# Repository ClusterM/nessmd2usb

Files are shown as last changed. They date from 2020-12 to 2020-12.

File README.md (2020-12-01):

# nessmd2usb
This adapter allows to connect Sega Mega Drive (Sega Genesis) and Famiclone (9-pin and 15-pin) controllers to PC via USB. Also it allows to connect 15-pin Famicom Light Gun (or clones) and use it with [fceux](https://github.com/taSVideos/fceux/) emulator.

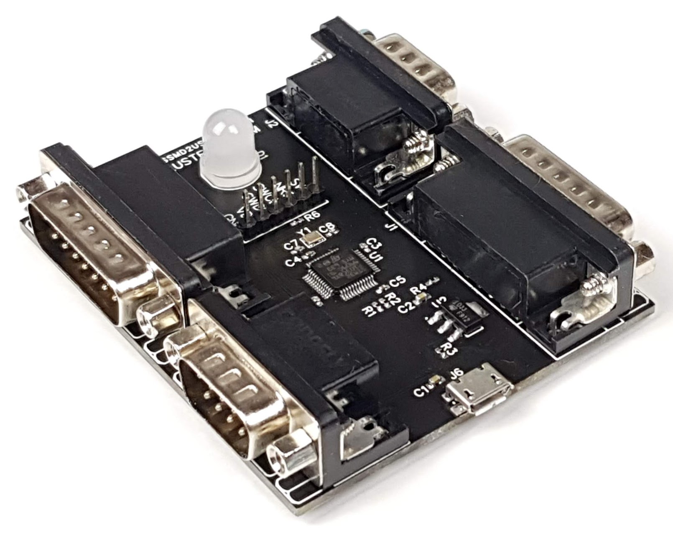
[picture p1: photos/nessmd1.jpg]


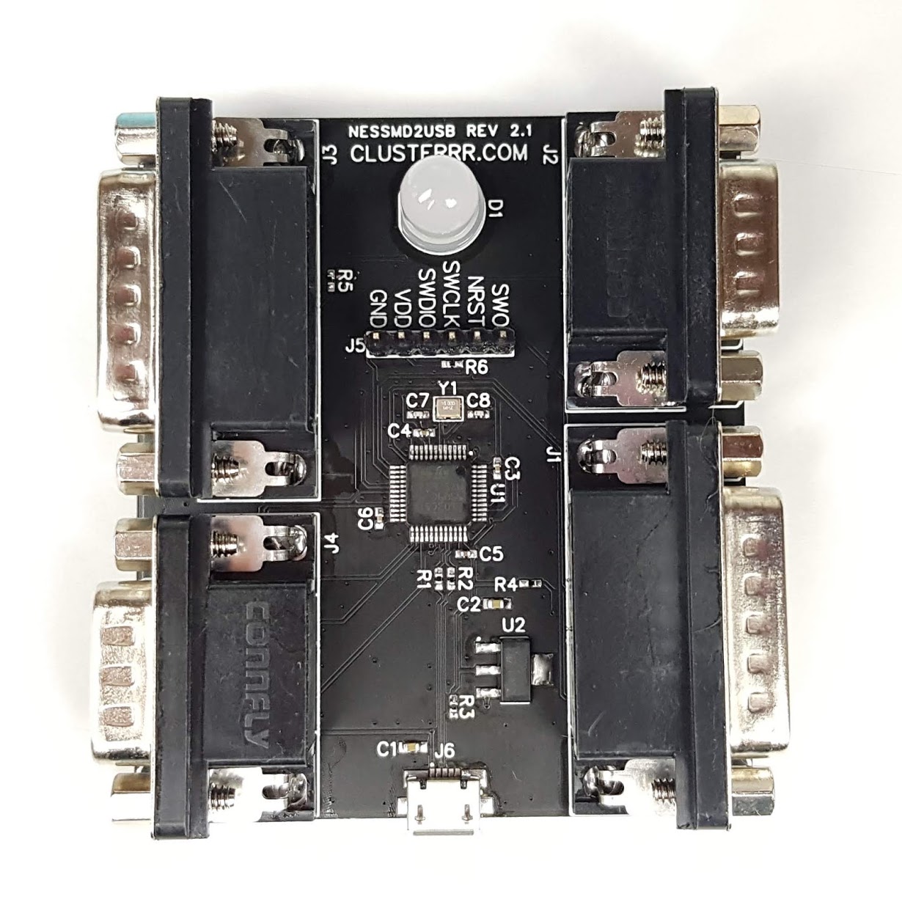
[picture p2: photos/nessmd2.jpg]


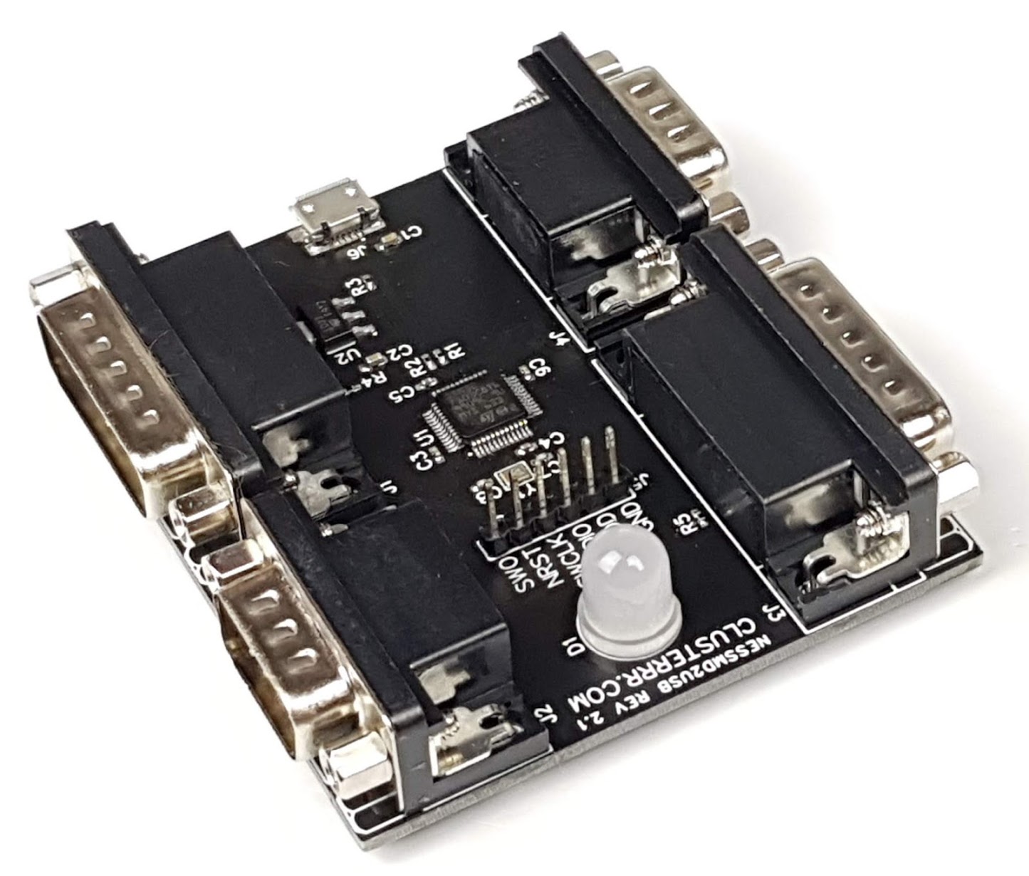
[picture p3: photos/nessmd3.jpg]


## Schematic:

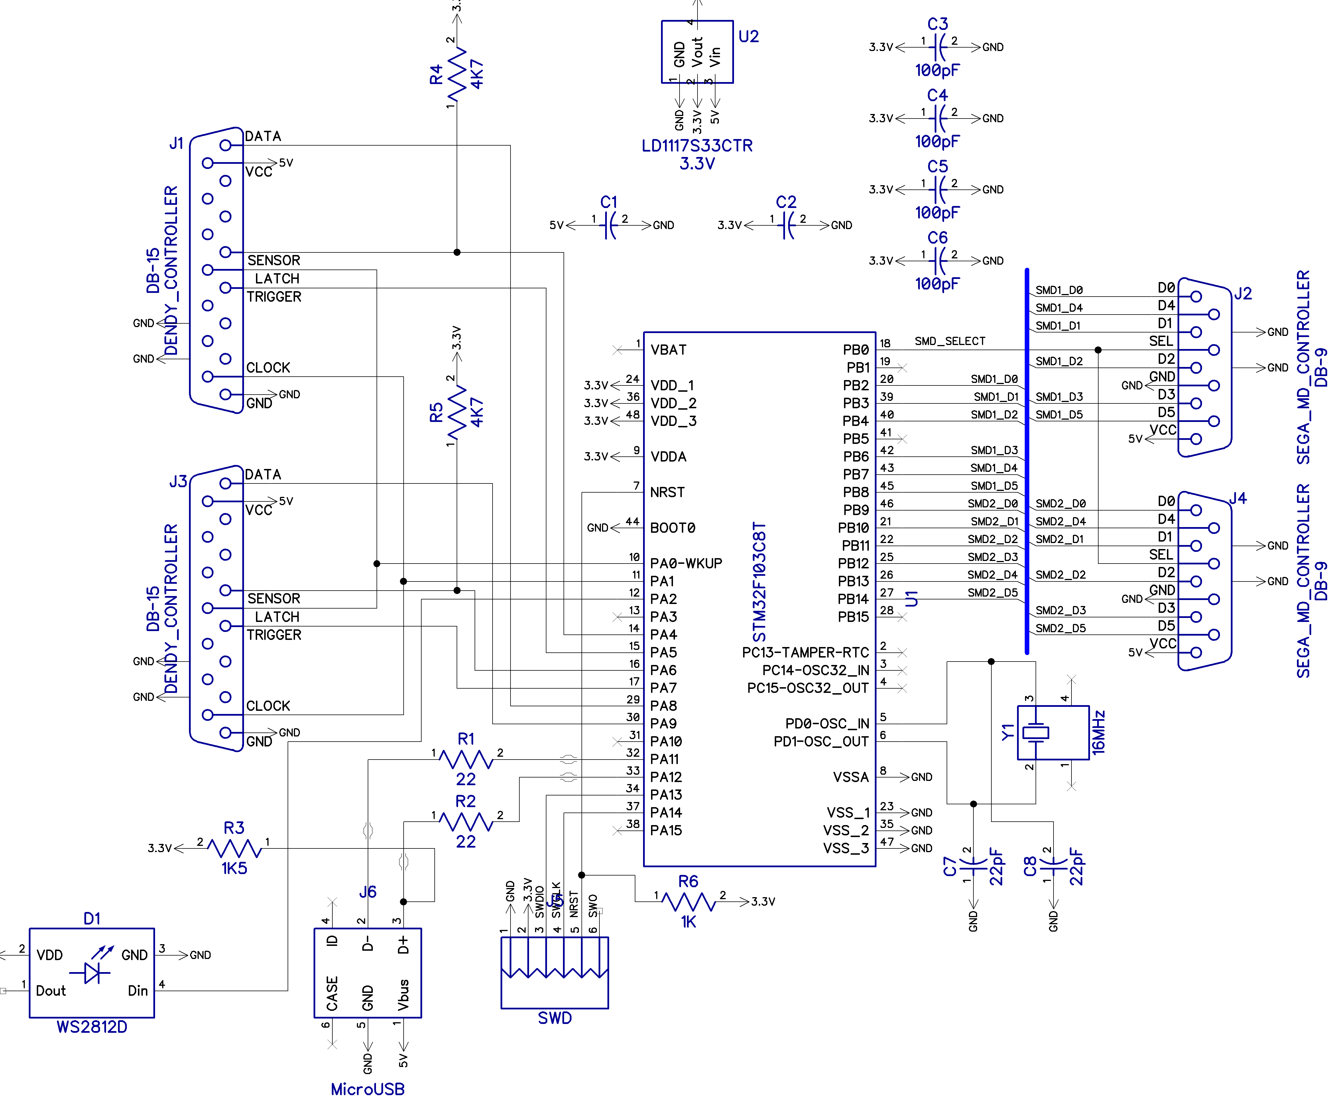
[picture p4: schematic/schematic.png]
Schematic


Bill of Materials:

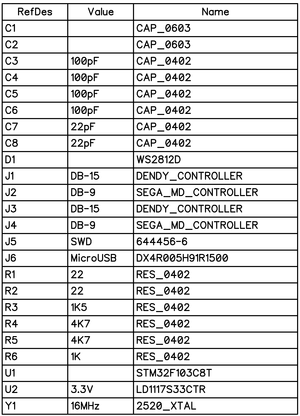
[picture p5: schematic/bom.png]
BoM


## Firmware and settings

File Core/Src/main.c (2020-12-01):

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
/* Includes ------------------------------------------------------------------*/
#include "main.h"
#include "usb_device.h"

/* USER CODE BEGIN Includes */
#include "usbd_customhid.h"
#include "gamepad.h"
/* USER CODE END Includes */

/* USER CODE BEGIN PD */
//#define USE_LIGHT_GUN
/* USER CODE END PD */

TIM_HandleTypeDef htim1;
TIM_HandleTypeDef htim2;
DMA_HandleTypeDef hdma_tim2_ch3;

/* USER CODE BEGIN PV */
extern USBD_HandleTypeDef hUsbDeviceFS;
static uint8_t pwm_values[8 * 3 + 1];
/* USER CODE END PV */

void SystemClock_Config(void);
static void MX_GPIO_Init(void);
static void MX_DMA_Init(void);
static void MX_TIM2_Init(void);
static void MX_TIM1_Init(void);
/* USER CODE BEGIN 0 */
static void update_led()
{
  //HAL_Delay(1);
  htim2.Instance->CR1 &= ~TIM_CR1_CEN;
  htim2.Instance->CCR3 = 0;
  htim2.Instance->CNT = 0;
  HAL_TIM_PWM_Start_DMA(&htim2, TIM_CHANNEL_3, (void*) pwm_values, sizeof(pwm_values));
}

static void set_led_color(uint8_t r, uint8_t g, uint8_t b)
{
//  r /= 4;
//  g /= 4;
//  b /= 4;
  uint8_t i;
  const uint8_t led = 0;
  for (i = 0; i < 8; i++)
    pwm_values[led * 8 * 3 + i] = ((r >> (7 - i)) & 1) ? 67 : 22;
  for (i = 0; i < 8; i++)
    pwm_values[led * 8 * 3 + 8 + i] = ((g >> (7 - i)) & 1) ? 67 : 22;
  for (i = 0; i < 8; i++)
    pwm_values[led * 8 * 3 + 16 + i] = ((b >> (7 - i)) & 1) ? 67 : 22;
  update_led();
}

static rgb hsv2rgb(hsv in)
{
  double hh, p, q, t, ff;
  long i;
  rgb out;
  if (in.s <= 0.0)
  {       // < is bogus, just shuts up warnings
    out.r = in.v;
    out.g = in.v;
    out.b = in.v;
    return out;
  }
  hh = in.h;
  while (hh > 360)
    hh -= 360;
  hh /= 60.0;
  i = (long) hh;
  ff = hh - i;
  p = in.v * (1.0 - in.s);
  q = in.v * (1.0 - (in.s * ff));
  t = in.v * (1.0 - (in.s * (1.0 - ff)));

  switch (i)
  {
  case 0:
    out.r = in.v;
    out.g = t;
    out.b = p;
    break;
  case 1:
    out.r = q;
    out.g = in.v;
    out.b = p;
    break;
  case 2:
    out.r = p;
    out.g = in.v;
    out.b = t;
    break;

  case 3:
    out.r = p;
    out.g = q;
    out.b = in.v;
    break;
  case 4:
    out.r = t;
    out.g = p;
    out.b = in.v;
    break;
  case 5:
  default:
    out.r = in.v;
    out.g = p;
    out.b = q;
    break;
  }
  return out;
}

static void set_axes(uint8_t dpad, Gamepad_Report_t *joystick_data)
{
  if (dpad & 1)
    joystick_data->y = -127;
  else if (dpad & 2)
    joystick_data->y = 127;
  else
    joystick_data->y = 0;
  if (dpad & 4)
    joystick_data->x = -127;
  else if (dpad & 8)
    joystick_data->x = 127;
  else
    joystick_data->x = 0;
}
/* USER CODE END 0 */

/**
  * @brief  The application entry point.
  * @retval int
  */
int main(void)
{
  /* MCU Configuration--------------------------------------------------------*/

  /* Reset of all peripherals, Initializes the Flash interface and the Systick. */
  HAL_Init();

  /* Configure the system clock */
  SystemClock_Config();

  /* Initialize all configured peripherals */
  MX_GPIO_Init();
  MX_DMA_Init();
  MX_USB_DEVICE_Init();
  MX_TIM2_Init();
  MX_TIM1_Init();
  /* USER CODE BEGIN 2 */
  HAL_TIM_Base_Start_IT(&htim1);

  /* USER CODE END 2 */

  /* Infinite loop */
  /* USER CODE BEGIN WHILE */
  Gamepad_Report_t joystick_data;
  uint8_t prev_trigger1 = 1;
  uint8_t prev_sensor1 = 1;
  uint8_t prev_trigger2 = 1;
  uint8_t prev_sensor2 = 1;

  while (1)
  {
    switch (hUsbDeviceFS.dev_state)
    {
    case USBD_STATE_CONFIGURED:
      break;
    case USBD_STATE_ADDRESSED:
      set_led_color(0xFF, 0xFF, 0x00);
      HAL_Delay(1);
      continue;
    default:
      set_led_color(0xFF, 0x00, 0x00);
      HAL_Delay(1);
      continue;
    }

    uint32_t smd_gamepad_data = get_smd_gamepad_decoded();
    uint16_t nes_gamepad_data = get_nes_gamepad_decoded();
#ifdef USE_LIGHT_GUN
    uint8_t trigger1 = HAL_GPIO_ReadPin(NES1_TRIGGER_GPIO_Port, NES1_TRIGGER_Pin);
    uint8_t sensor1 = HAL_GPIO_ReadPin(NES1_SENSOR_GPIO_Port, NES1_SENSOR_Pin);
    uint8_t trigger2 = HAL_GPIO_ReadPin(NES2_TRIGGER_GPIO_Port, NES2_TRIGGER_Pin);
    uint8_t sensor2 = HAL_GPIO_ReadPin(NES2_SENSOR_GPIO_Port, NES2_SENSOR_Pin);
#else
    const uint8_t trigger1 = 0;
    const uint8_t sensor1 = 0;
    const uint8_t trigger2 = 0;
    const uint8_t sensor2 = 0;
#endif

    TIM1->CNT = 0;

    joystick_data.report_id = 1;
    joystick_data.buttons = (nes_gamepad_data & 0x0F) | (trigger1 << 4) | (sensor1 << 5);
    set_axes((nes_gamepad_data >> 4) & 0x0F, &joystick_data);
    USBD_CUSTOM_HID_SendReport(&hUsbDeviceFS, (void*) &joystick_data, sizeof(joystick_data));
    while (((USBD_CUSTOM_HID_HandleTypeDef*) hUsbDeviceFS.pClassData)->state != CUSTOM_HID_IDLE)
    {
      if (TIM1->CNT > 50000)
        break;
    }

    joystick_data.report_id = 2;
    joystick_data.buttons = smd_gamepad_data & 0xFF;
    set_axes((smd_gamepad_data >> 8) & 0x0F, &joystick_data);
    USBD_CUSTOM_HID_SendReport(&hUsbDeviceFS, (void*) &joystick_data, sizeof(joystick_data));
    while (((USBD_CUSTOM_HID_HandleTypeDef*) hUsbDeviceFS.pClassData)->state != CUSTOM_HID_IDLE)
    {
      if (TIM1->CNT > 50000)
        break;
    }

    joystick_data.report_id = 3;
    joystick_data.buttons = ((nes_gamepad_data >> 8) & 0x0F) | (trigger2 << 4) | (sensor2 << 5);
    set_axes((nes_gamepad_data >> 12) & 0x0F, &joystick_data);
    USBD_CUSTOM_HID_SendReport(&hUsbDeviceFS, (void*) &joystick_data, sizeof(joystick_data));
    while (((USBD_CUSTOM_HID_HandleTypeDef*) hUsbDeviceFS.pClassData)->state != CUSTOM_HID_IDLE)
    {
      if (TIM1->CNT > 50000)
        break;
    }

    joystick_data.report_id = 4;
    joystick_data.buttons = (smd_gamepad_data >> 16) & 0xFF;
    set_axes((smd_gamepad_data >> 24) & 0x0F, &joystick_data);
    USBD_CUSTOM_HID_SendReport(&hUsbDeviceFS, (void*) &joystick_data, sizeof(joystick_data));
    while (((USBD_CUSTOM_HID_HandleTypeDef*) hUsbDeviceFS.pClassData)->state != CUSTOM_HID_IDLE)
    {
      if (TIM1->CNT > 50000)
        break;
    }

    if ((sensor1 && !prev_sensor1) || (sensor2 && !prev_sensor2))
    {
      set_led_color(0xFF, 0xFF, 0xFF);
    } else if ((trigger1 && !prev_trigger1) || (trigger2 && !prev_trigger2))
    {
      set_led_color(0x40, 0x40, 0);
    } else
    {
      uint8_t button_count = 0;
      uint8_t i;
      for (i = 0; i < 16; i++)
        if ((nes_gamepad_data >> i) & 1)
          button_count++;
      for (i = 0; i < 32; i++)
        if ((smd_gamepad_data >> i) & 1)
          button_count++;
      hsv v;
      v.h = 100 + button_count * 15;
      v.s = 1;
      v.v = 0.1 + 0.05 * button_count;
      if (v.v > 1)
        v.v = 1;
      rgb r = hsv2rgb(v);
      if (r.r > 1)
        r.r = 1;
      if (r.g > 1)
        r.g = 1;
      if (r.b > 1)
        r.b = 1;
      set_led_color(r.r * 0xFF, r.g * 0xFF, r.b * 0xFF);
    }

    prev_trigger1 = trigger1;
    prev_sensor1 = sensor1;
    prev_trigger2 = trigger2;
    prev_sensor2 = sensor2;

    // 1ms delay
    while (TIM1->CNT < 1000)
    {
    }

    /* USER CODE END WHILE */

    /* USER CODE BEGIN 3 */
  }
  /* USER CODE END 3 */
}

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


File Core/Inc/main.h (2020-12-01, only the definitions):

#define NES_LATCH_Pin GPIO_PIN_0
#define NES_LATCH_GPIO_Port GPIOA
#define NES_CLOCK_Pin GPIO_PIN_1
#define NES_CLOCK_GPIO_Port GPIOA
#define LED_Pin GPIO_PIN_2
#define LED_GPIO_Port GPIOA
#define NES1_SENSOR_Pin GPIO_PIN_4
#define NES1_SENSOR_GPIO_Port GPIOA
#define NES1_TRIGGER_Pin GPIO_PIN_5
#define NES1_TRIGGER_GPIO_Port GPIOA
#define NES2_SENSOR_Pin GPIO_PIN_6
#define NES2_SENSOR_GPIO_Port GPIOA
#define NES2_TRIGGER_Pin GPIO_PIN_7
#define NES2_TRIGGER_GPIO_Port GPIOA
#define SMD_SELECT_Pin GPIO_PIN_0
#define SMD_SELECT_GPIO_Port GPIOB
#define SMD1_D0_Pin GPIO_PIN_2
#define SMD1_D0_GPIO_Port GPIOB
#define SMD2_D1_Pin GPIO_PIN_10
#define SMD2_D1_GPIO_Port GPIOB
#define SMD2_D2_Pin GPIO_PIN_11
#define SMD2_D2_GPIO_Port GPIOB
#define SMD2_D3_Pin GPIO_PIN_12
#define SMD2_D3_GPIO_Port GPIOB
#define SMD2_D4_Pin GPIO_PIN_13
#define SMD2_D4_GPIO_Port GPIOB
#define SMD2_D5_Pin GPIO_PIN_14
#define SMD2_D5_GPIO_Port GPIOB
#define NES1_DATA_Pin GPIO_PIN_8
#define NES1_DATA_GPIO_Port GPIOA
#define NES2_DATA_Pin GPIO_PIN_9
#define NES2_DATA_GPIO_Port GPIOA
#define SMD1_D1_Pin GPIO_PIN_3
#define SMD1_D1_GPIO_Port GPIOB
#define SMD1_D2_Pin GPIO_PIN_4
#define SMD1_D2_GPIO_Port GPIOB
#define SMD1_D3_Pin GPIO_PIN_6
#define SMD1_D3_GPIO_Port GPIOB
#define SMD1_D4_Pin GPIO_PIN_7
#define SMD1_D4_GPIO_Port GPIOB
#define SMD1_D5_Pin GPIO_PIN_8
#define SMD1_D5_GPIO_Port GPIOB
#define SMD2_D0_Pin GPIO_PIN_9
#define SMD2_D0_GPIO_Port GPIOB

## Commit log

2016-07-01 Support for 9-pin Dendy controllers
2017-03-24 Цена
2017-05-27 More correct LATCH
    [BoardOutline.gbr, Bottom.gbr, BottomMask.gbr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]
2018-08-13 Updated for new LUFA, fixes, new gerbers
    [BoardOutline.gbr, Bottom.gbr, BottomMask.gbr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]
2020-12-01 Totally new version, using STM32 now
    [1 - Top.gbr, 2 - Bottom.gbr, BoardOutline.gbr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]
2020-12-01 Added Bill of Materials
2020-12-01 Resized bom.png

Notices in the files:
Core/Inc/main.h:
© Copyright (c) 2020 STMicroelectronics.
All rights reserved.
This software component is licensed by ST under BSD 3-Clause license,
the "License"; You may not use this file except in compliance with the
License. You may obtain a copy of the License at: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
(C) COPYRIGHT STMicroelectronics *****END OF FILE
